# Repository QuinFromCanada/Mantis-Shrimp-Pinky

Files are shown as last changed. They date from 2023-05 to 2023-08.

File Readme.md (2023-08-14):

## Credit:

This is a fork of https://github.com/PinkysRevenge/Mantis-Shrimp-Pinky/ Awsome design Pinky!

Original idea and design by nehilo on GitHub. Can be found here: https://drive.google.com/file/d/1KHLhYUvODkVxrdv76lzVsDeCy6QFU4UK/view
Credit to @theotherjimmy#8823 on Discord for the initial modifications
The Sailfin design is thanks to CROXY3d: https://github.com/CroXY3D/Sailfin-Extruder

## Description:

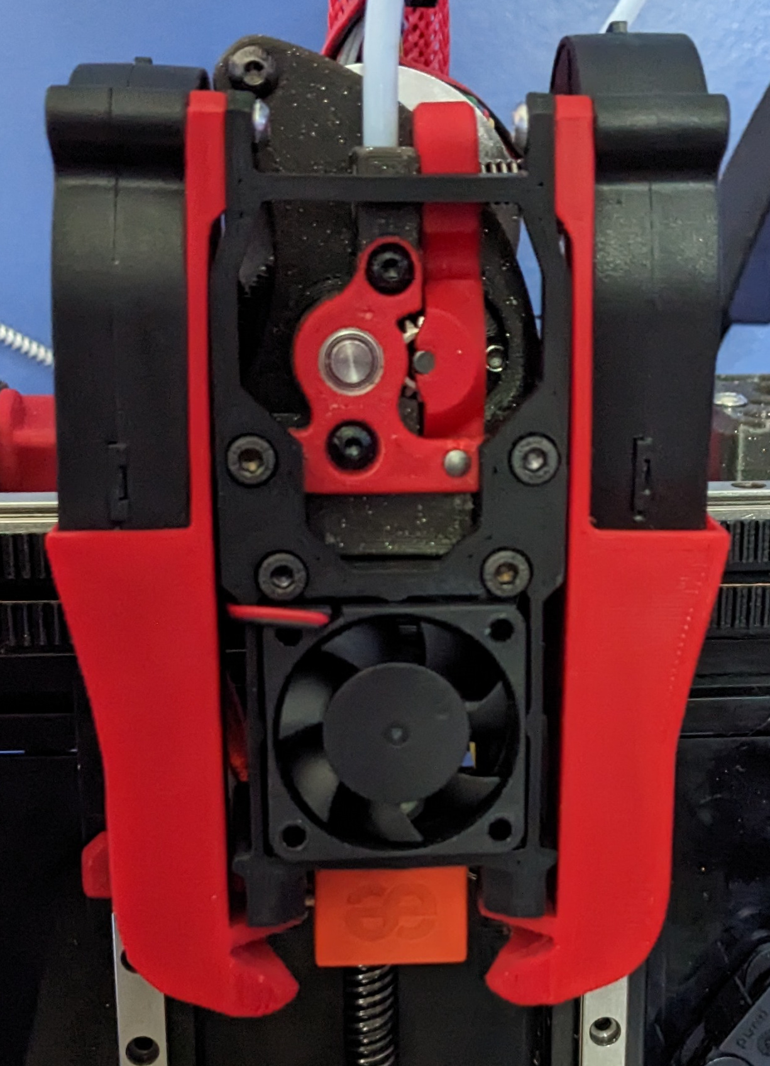
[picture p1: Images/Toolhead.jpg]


I love the design however, I had issues printing with ABS using the Dragon Toolhead.
My theory was that this was caused by the air from the hotend fan blowing across the top of the heat block.
So I redesigned the Cage (Mantis-Shrimp_Pinky Body - Alternate for Phaetus Dragon Hotend for ABS printing).

The rest of the project uses Pinky's files.

I Remade the Design in FreeCAD - Realthunder Branch  https://github.com/realthunder/FreeCAD/releases because I love FreeCAD and I wanted a model with more freedom to modify key features down the road.

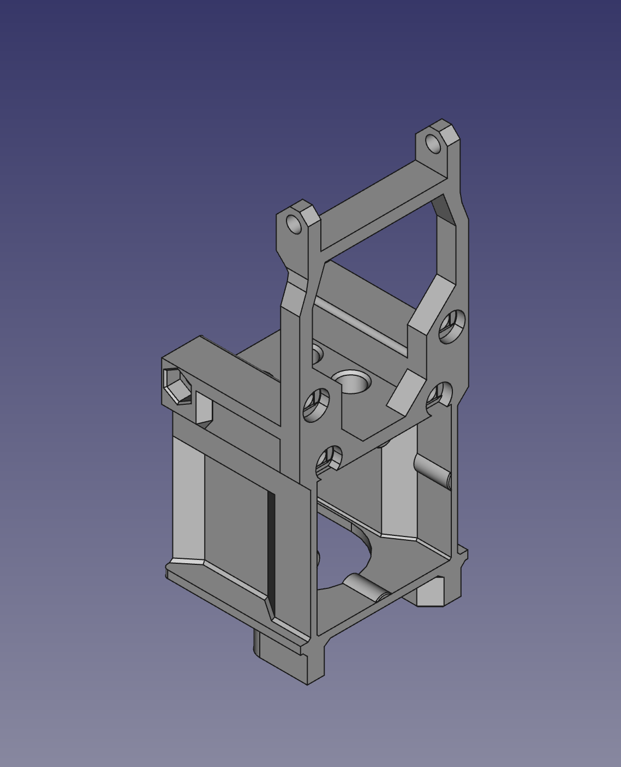
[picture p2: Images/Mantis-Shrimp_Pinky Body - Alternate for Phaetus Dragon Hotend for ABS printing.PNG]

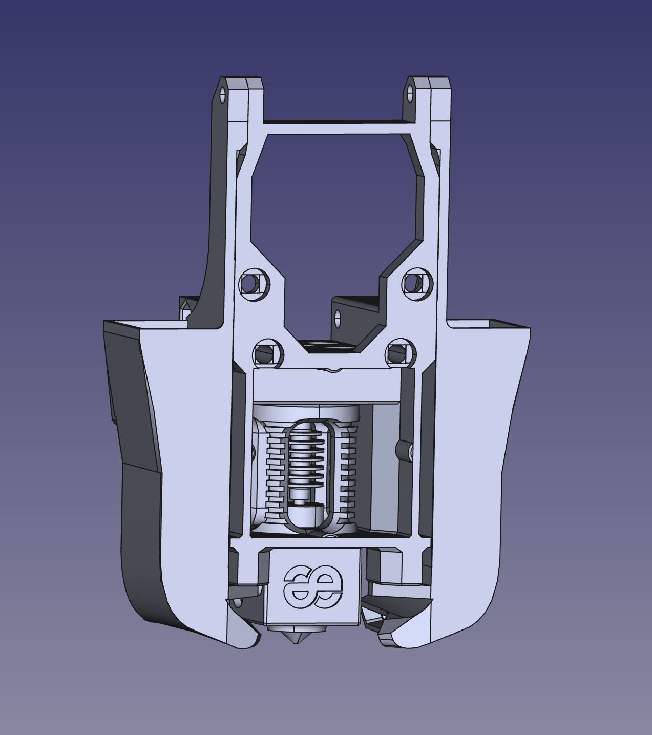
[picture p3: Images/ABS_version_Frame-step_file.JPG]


## Simulations:

Im also messing around with some Airflow Simulations which are available at [https://www.simscale.com/projects/quinfromcanada/mantis_shrimp_-_copy/]

## Hardware List (Still working on it)

For Cage and Fans:
- 1x NEMA14 36mm pancake Motor with 10 tooth gear (Reuse from old hotend)
- 2x 5015 Axial Fans 
- 1x 3010 Blower Fan (Reuse from old hotend)
- 4x 3MM Heatset Inserts
- 1x M3 Nut
- 5x M3x35mm
- 2x M3x12mm
- 2x M3x8mm
- 2-4x Hotend mount screws (i think they are M2x10)
- 28.75 - 29.25mm Bowden tube 2mm ID 4mm OD

Sailfin Hardware: 
- 1x BMG hardware kit (Reuse from old hotend)
- ... (comming soon, need to take mine apart to see what I used)

ADXL345 Hardware:
- Adafruit ADXL345 (thats the one I use)
- 2x M2 Nuts
- 2x M2x6mm or M2x8mm
- 2x M3x40mm

## What parts to Print:

Sharkfin:
- Mantis-Shrimp Sailfin Lever   (Accent Colour)
- Mantis Spring Pinky Front Sailfin Panel v#     (Accent Colour)
- Mantis-Shrimp - Pink - Sailfin rear for stock X carriage
- Mantis-Shrimp Sailfin Mid
- Mantis-Shrimp Sailfin Rear

X Carriage: (optional but Works really good)
- Mantis-Shrimp_Pink Optional X Carriage

OG design:
- Mantis-Shrimp_Pinky Body r2 v20
- Mantis-Shrimp_Pinky r2 L Duct v##
- Mantis-Shrimp_Pinky r2 R Duct v##

Quins Remix:
- Mantis-Shrimp_Pinky Body - Alternate for Phaetus Dragon Hotend for ABS printing v#
- Mantis-Shrimp_Pinky Duct L - Alternate for Pheatus Dragon Hotend v##
- Mantis-Shrimp_Pinky Duct R - Alternate for Pheatus Dragon Hotend v##

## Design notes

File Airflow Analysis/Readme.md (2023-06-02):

## Description:

I made these Simulations in order to help me optimize airflow for this project.  They are available to the public at https://www.simscale.com/projects/quinfromcanada/mantis_shrimp_-_copy/

My hope here is that someone finds this interesting.

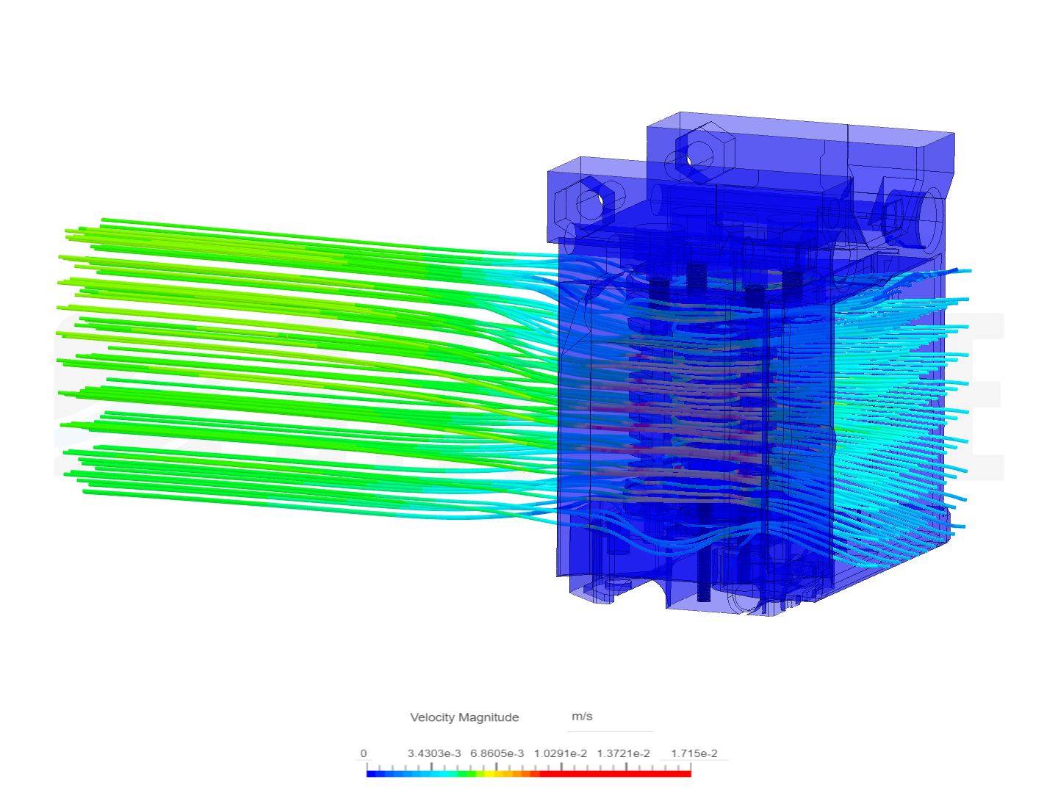
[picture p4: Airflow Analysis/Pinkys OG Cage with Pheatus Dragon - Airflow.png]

This is how Airflow travels from the parts cooling fan on the OG design when you use a Dragon Toolhead with them.  As you can see some of the airflow fromt eh fan flows across the top of the heater block, reducing its ability to heat the fillament.

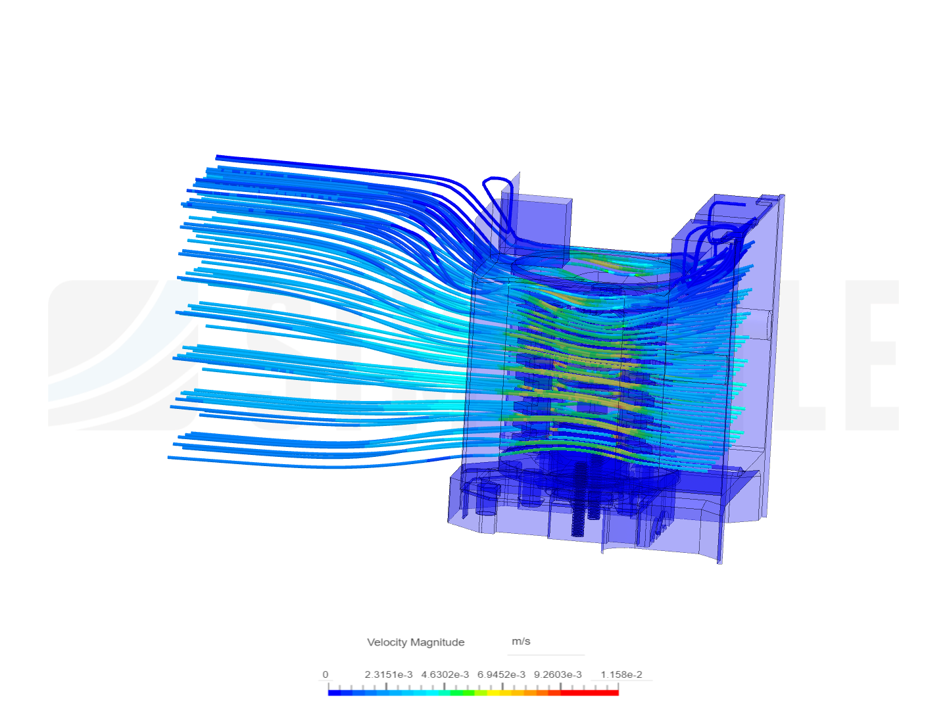
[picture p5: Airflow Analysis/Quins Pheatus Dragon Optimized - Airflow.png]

In my design I moved the fan up, dropped the hot end down and, added a skirt to prevent drafts from hitting the top of the heater block. This increases the ability to heat.

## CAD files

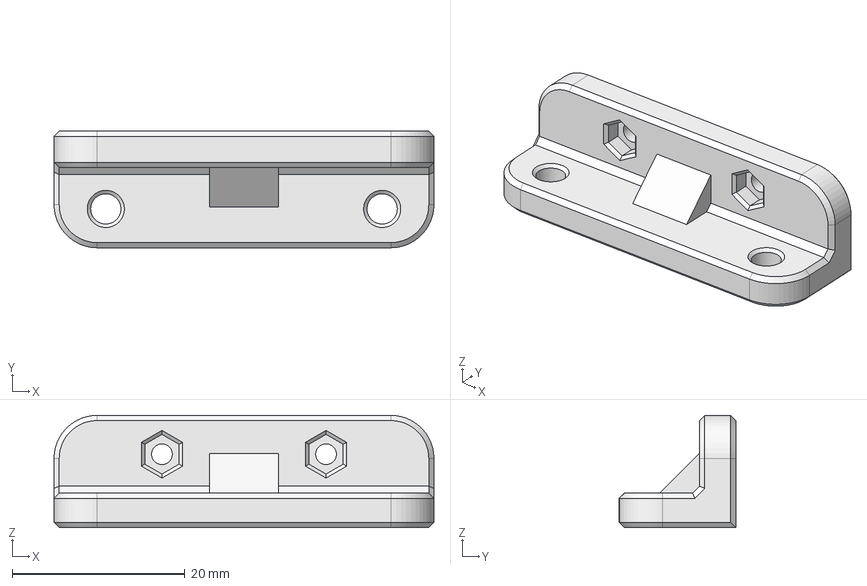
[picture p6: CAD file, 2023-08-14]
CAD/ADXL345_Mounts/Adafruit ADXL345 holder.step
44.0 x 13.5 x 13.0 mm

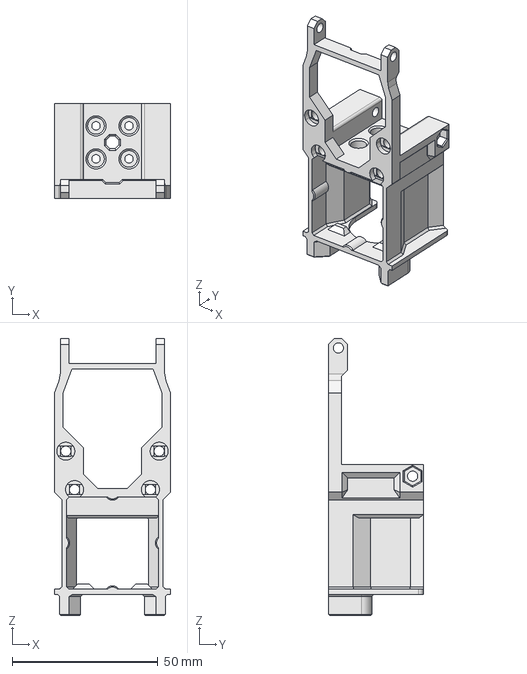
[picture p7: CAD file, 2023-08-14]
CAD/Quins_Mantis_Shrimp_Remix/Mantis-Shrimp_Pinky Body - Alternate for Phaetus Dragon Hotend for ABS printing v4.step
39.8 x 32.5 x 95.0 mm

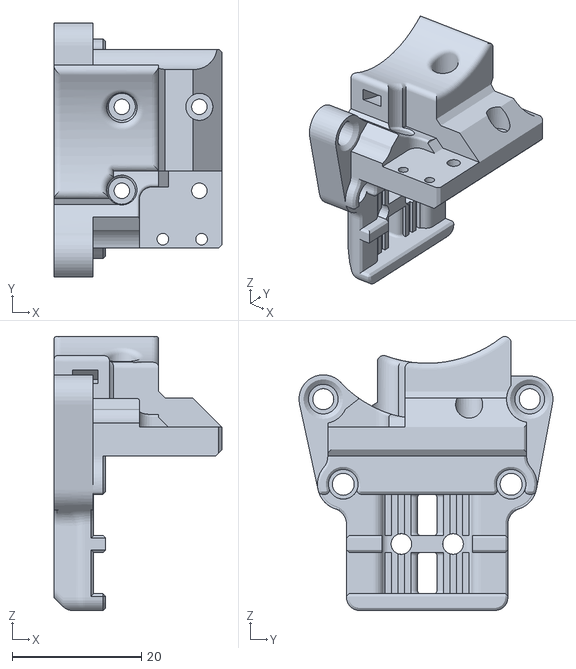
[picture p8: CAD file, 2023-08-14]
STLs/Mantis-Shrimp_Pink Optional X Carriage.stl
26.0 x 39.3 x 42.4

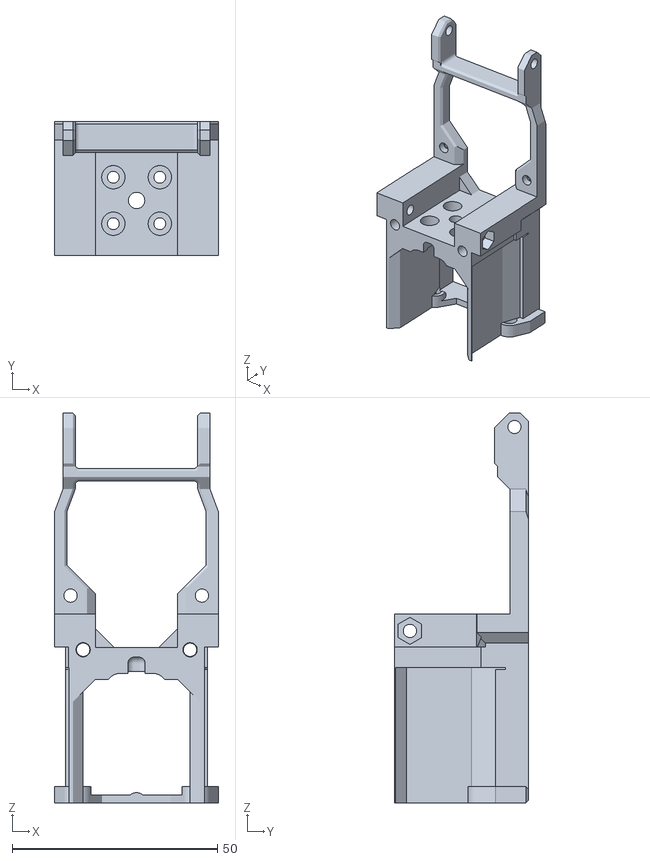
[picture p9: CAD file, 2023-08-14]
STLs/Pinks_OG_Mantis_Shirimp/Mantis-Shrimp_Pinky Body r2 v20.stl
40.0 x 32.5 x 94.9

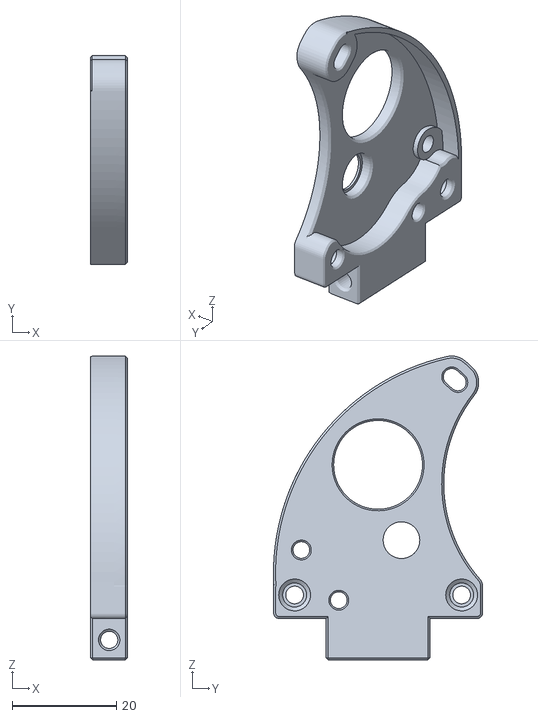
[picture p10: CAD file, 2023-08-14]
STLs/Sailfin/Mantis-Shrimp - Pink - Sailfin rear for stock X carriage.stl
7.08 x 40.0 x 58.2

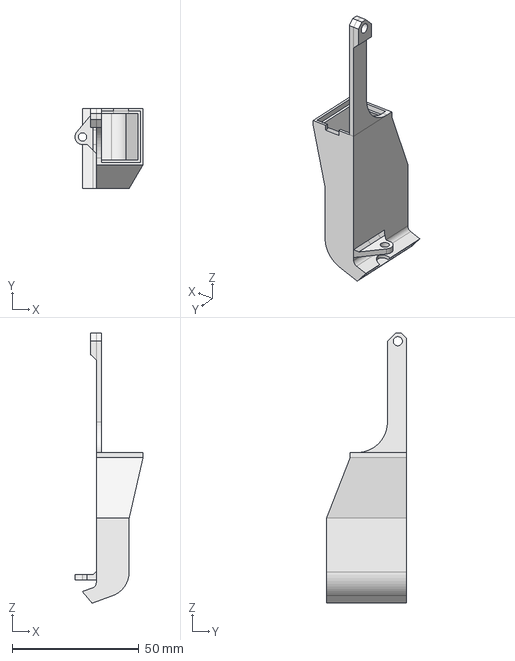
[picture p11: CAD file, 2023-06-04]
CAD/Quins_Mantis_Shrimp_Remix/Mantis-Shrimp_Pinky Duct L - Alternate for Pheatus Dragon Hotend v1.step
26.8 x 31.5 x 106.5 mm

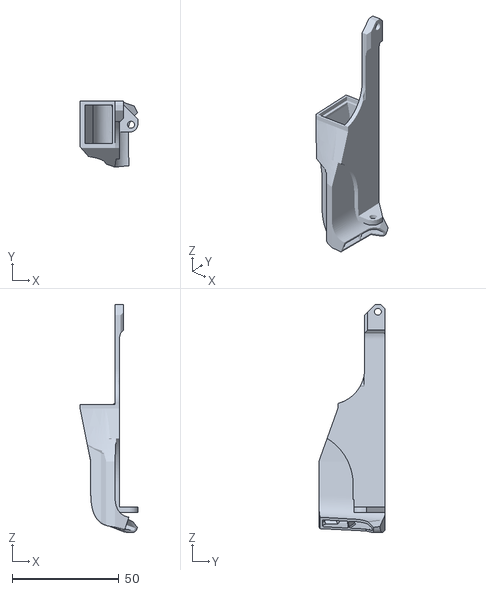
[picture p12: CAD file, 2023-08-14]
STLs/Pinks_OG_Mantis_Shirimp/Mantis-Shrimp_Pinky r2 R Duct v16.stl
27.1 x 31.1 x 106.8

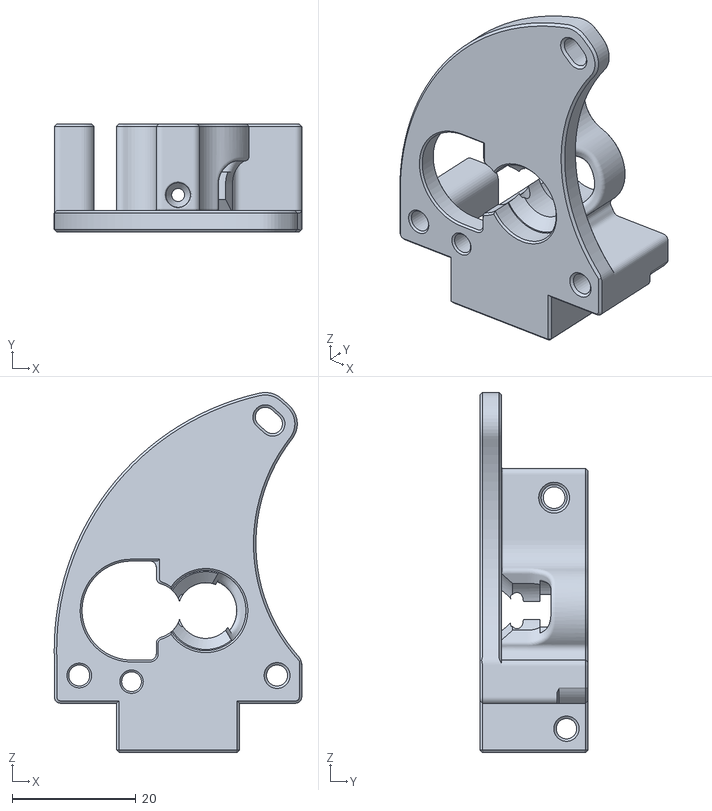
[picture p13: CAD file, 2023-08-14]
STLs/Sailfin/Mantis-Shrimp Sailfin Mid.stl
40.0 x 17.5 x 58.2

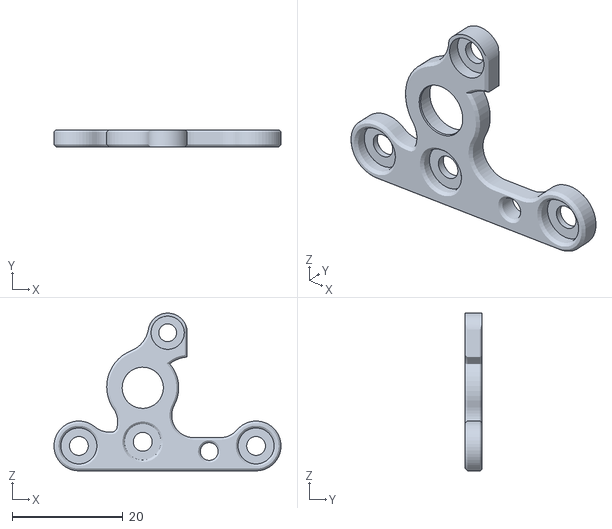
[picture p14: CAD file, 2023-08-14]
STLs/Sailfin/Mantis Spring Pinky Front Sailfin Panel v1.stl
41.0 x 3.00 x 28.5

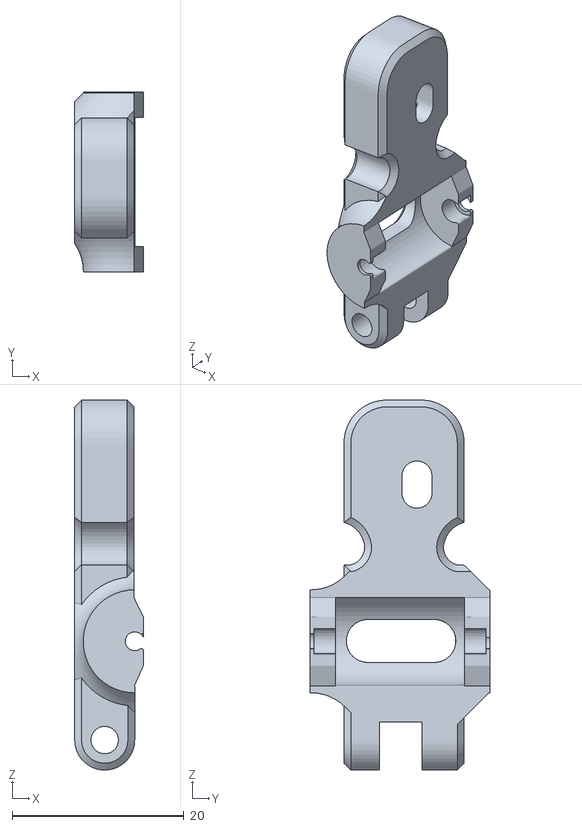
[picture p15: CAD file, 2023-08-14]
STLs/Sailfin/Mantis-Shrimp Sailfin Lever.stl
8.00 x 21.0 x 43.1

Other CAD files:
STLs/Quins_Mantis_Shrimp_Remix/Mantis-Shrimp_Pinky Body - Alternate for Phaetus Dragon Hotend for ABS printing.stl
STLs/Sailfin/Mantis-Shrimp Sailfin Rear.stl
STLs/Pinks_OG_Mantis_Shirimp/Mantis-Shrimp_Pinky r2 L Duct v15.stl
CAD/ADXL345_Mounts/Adafruit ADXL345 holder.FCStd
CAD/Quins_Mantis_Shrimp_Remix/Mantis-Shrimp_Pinky Body - Alternate for Phaetus Dragon Hotend for ABS printing v4.FCStd
CAD/Quins_Mantis_Shrimp_Remix/Mantis-Shrimp_Pinky Duct L - Alternate for Pheatus Dragon Hotend v1.FCStd
STLs/ADXL345_Mounts/Adafruit ADXL345 holder.stl
STLs/Quins_Mantis_Shrimp_Remix/Mantis-Shrimp_Pinky Duct L - Alternate for Pheatus Dragon Hotend v1.stl

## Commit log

2023-05-17 Add files via upload
    Redesign of the original cage in order to print at higher temps 250deg.
    [Mantis-Shrimp_Pinky Body - Alternate for Phaetus Dragon Hotend for ABS printing.FCStd, Mantis-Shrimp_Pinky Body - Alternate for Phaetus Dragon Hotend for ABS p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]
2023-05-27 Minor Tweeks
    Added
    - Hotend HF .step file (from Pheatus Thingiverse Page, slight edit to remove E3D style mount.
    - Added Hotend, frame and blower Step file.
    - Small update to cage, upper Fan pillar + holes moved moved down by 0.75mm.
    [Mantis-Shrimp_Pinky Body - Alternate for Phaetus Dragon Hotend for ABS printing.FCStd, Mantis-Shrimp_Pinky Body - Alternate for Phaetus Dragon Hotend for ABS p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]
2023-06-04 Update Readme.md
    Added 1st draft of the parts list, and a list of what to print.
2023-06-04 v1 duct added.
    v1 of a duct redesign for Dragon hotend, seems to heat much better, in testing.
    [Mantis-Shrimp_Pinky Duct L - Alternate for Pheatus Dragon Hotend v1.FCStd, Mantis-Shrimp_Pinky Duct L - Alternate for Pheatus Dragon Hotend v1.step, Mantis-Shr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]
2023-07-30 Update Readme.md
    Put bowden tube in wrong area. .. fixed
2023-08-11 Added Clearance
    Small Update, to make inserting the sailfin into the cage while the cage a bit easier, especially when it is still installed in the printer.
    - Top bar reduced by 1mm in depth.
    - Cutout added to help with the top screw clearance.
    [Mantis-Shrimp_Pinky Body - Alternate for Phaetus Dragon Hotend for ABS printing.FCStd, Mantis-Shrimp_Pinky Body - Alternate for Phaetus Dragon Hotend for ABS p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]
2023-08-14 V4 remix release and Repo Cleanup
    Released V4 of my Remix change, Changes include:
    - Bottom bar is now .2mm thicker to be a multiple of .4mm.
    - Made the Fan pressure mounts .2mm tighter (at 500mm/s 12000 accel I would sometimes have the fan come loose).
    - Added fan insert stoppers at the bottom.
    - Made the upper bar .4mm thinner to make inserting the sailfin easier.
    Added ADXL345 mount into the repo.
    [Adafruit ADXL345 holder.FCStd, Adafruit ADXL345 holder.step, Adafruit ADXL345 holder.stl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]
2023-08-14 Update Readme.md
    Added Hardware for ADXL mount.
